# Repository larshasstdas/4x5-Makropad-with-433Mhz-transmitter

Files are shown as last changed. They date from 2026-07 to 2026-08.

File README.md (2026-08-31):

# 4x5-Makropad-with-433Mhz-transmitter

WhatsApp Image 2026-08-31 at 16 35 43

This project is about a Makropad that has 20 keys in a 4x5 matrix with a 433Mhz transmitter that is used to power my PC. Every key has an indiviually LED that will be changeable with an app on the PC.

---

## Motivation

In a previous project i made a [wireless power switch for my PC](https://github.com/larshasstdas/Remote-PC-Power-Switch) but as it is only a singular button it feels quite chunky. And i also always had the interest in controlling my LED strips in my room and my PC lighting i got the idea of making a makropad that combines all those features. It should also have usual makropad funktion like adjusting the sound volume and shortcuts. 

---

## How it works

The RP2040 registers which key is pressed. It send that information to a daemon on my pc which has the information of what that key actually does. The programm can also send information to the makropad to what each LED should be. If the button is pressed that is used for turning the PC on the daemon can't answer because the PC is turned of. If the RP2040 does not get a signal back it sends the signal to the stx882 module resulting in turning the PC on. It can use a different function afterwards because the daemon can answer if that button is pressed.

---

## PCB

I am using the RP2040 as a microcontroller it has everything i need and can be soldered onto the pcb with castelladed pads. The same goes for the 433MHz transmitter module the STX882. I also have the option to add a display but I am leaving that open as of now. Furthermore there are Hotswap pockets so i can easily spwap broken switches. And for the LED I am using the SK6812MINI-E, a reverse mount LED. The switches are using a matrix so they need less pins and the LEDs are in an addressable LED chain.

All the PCB files are in the KiCad Folder.



---

## Bill of Materials

Bought the parts so they would be as cheap as possible. Did not buy the display pins as i do not plan on using it for now. It is just an option for the future.

| Part | Description | Qty | Unit Price | Link |
| --- | --- | --- | --- | ---- |
| Waveshare RP2040-Zero | MCU module, USB-C, castellated | 1 | 4.00€ | [Eckstein](https://eckstein-shop.de/WaveShare-RP2040-Zero-MCU-Board-Mini-Version) |
| STX882 | 433 MHz ASK/OOK transmitter (+ spring antenna) | 1 | 6.99€ | [Amazon](https://www.amazon.de/dp/B0D3TGHD7H/) |
| SK6812MINI-E | Addressable RGB LED, reverse mount | 20  | 6.59€ | [Amazon](https://www.amazon.de/gp/product/B0DQ8HXSQS/) |
| 74AHCT1G125 | Level shifter 3.3V→5V for LED data line (SOT-353) | 1 | 0.20€ | [Reichelt](https://www.reichelt.de/de/de/shop/produkt/tristate-buffer_enable_2_5_5_v_sot-353-5-219156) |
| Gateron Pro Milky Yellow  | Linear 5-pin hotswap switch | 20  | 6.80€ | [inputgear](https://inputgear.de/products/gateron-pro-milky-yellow-switch?variant=56226523775320) |
| Kailh MX Hotswap Socket | MX hotswap socket (THT) | 20  | 7.83€ | [Amazon](https://www.amazon.de/gp/product/B07K8CCMQZ/) |
| Keycaps 1u | Opaque keycaps (light shows around base) | 20  | 10.71€ | [Amazon](https://www.amazon.de/gp/product/B0F1YQGJ35/) |
| 1N4148W | Matrix diode, 100V 150mA (SOD-123) | 20  | 0.40€ | [Reichelt](https://www.reichelt.de/de/de/shop/produkt/kleinsignal-schalt-diode_100_v_150_ma_sod-123-219382) |
| 100nF capacitor | Decoupling, X7R 50V (0603) | 21  | 0.63€ | [Reichelt](https://www.reichelt.de/de/de/shop/produkt/mlcc_0603_100nf_50v_x7r_-5_-429035) |
| 330 Ω resistor | LED data-line series resistor (0603) | 1 | 0.02€ | [Reichelt](https://www.reichelt.de/de/de/shop/produkt/smd-widerstand_0603_330_ohm_100_mw_1_-89424) |
| I2C display header | 4-pin Dupont, optional display (2.54mm) | 1 | - | – |
| PCB | pcb ordered on jlcpcb | 1 | 33.67€ | – |
| 3D-printed case | Top + bottom, filament | 1 | ~1.00€ | – |
| **Total** | | | **78.84€** | |

---

## Case

The CAD files for the case are in the CAD folder. There are the source files from creo parametric (my cad tool), the step-files and the stl-files each in one folder. They contain a file for the top and the bottom part and the Creo folder also has the assembly file for the makropad which you can see below. The only files needed for 3D.printing are the case_bottom and cas_top files. The rest are only used for the assembly.



---

## How it is build

The pcb is soldered on a hot plate and some parts by soldering iron. The switches get placed into the hotswaps and once that is done it is placed in the bottom half of the case. Afterwards the top part gets fitted onto the bottom part and the keycaps get pressed onto the switches.

---

## How to flash

I used VS Code with platform.io to flash the RP2040. Just connect with an USB-C cable and press the flash button bottom left.

---

## How to set up the daemon

1. Create and activating the venv. For that first use "cd C:\path\...\Makropad\Daemon", then "python -m venv venv" and last "venv\Scripts\Activate.ps1".
2. Install all the libarys. The versions are in the requirements.txt
3. Select the right COM port in the config.json
4. Press "Win + R" and type "shell:startup" so the startup folder opens.
5. Rightclick and add a new shortcut. Enter the location "C:\path\...\Makropad\Daemon\venv\Scripts\pythonw.exe main.py" for the shortcut. When you press enter you can choose a name.
6. Rightclick the new shortcut and go to properties. In "Start in" enter the daemon folder "C:\path\...\Makropad\Daemon" it must not include "\venv\Scripts".
7. Apply the changes.

---

## Files

```
CAD/               Creo source files (top, bottom, pcb and assembly), stl files (top & bottom), step files
Deamon/            Python files for the daemon, requirements.txt with all the libary versions  
KiCad/             KiCad files, Gerber files (also as .zip), libarys, Pick&Place
RP2040_Code/       Platform.io project with all files needed for flashing the RP2040
BOM.csv
```

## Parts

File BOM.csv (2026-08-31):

Part,Description,Quantity,Price (EUR),Link
Waveshare RP2040-Zero,MCU module USB-C castellated (no-header variant),1,4.00,https://eckstein-shop.de/WaveShare-RP2040-Zero-MCU-Board-Mini-Version
STX882,433 MHz ASK/OOK transmitter module (+ spring antenna),1,6.99,https://www.amazon.de/dp/B0D3TGHD7H/
SK6812MINI-E,Addressable RGB LED with integrated driver (reverse mount),20,6.59,https://www.amazon.de/gp/product/B0DQ8HXSQS/
74AHCT1G125,Single tri-state buffer / level shifter 3.3V->5V (SOT-353-5),1,0.20,https://www.reichelt.de/de/de/shop/produkt/tristate-buffer_enable_2_5_5_v_sot-353-5-219156
Gateron Pro Milky Yellow,Linear 5-pin hotswap switch,20,6.80,https://inputgear.de/products/gateron-pro-milky-yellow-switch?variant=56226523775320
Kailh MX Hotswap Socket,MX hotswap socket (THT),20,7.83,https://www.amazon.de/gp/product/B07K8CCMQZ/
Keycaps 1u,Opaque keycaps (light shows around switch base),20,10.71,https://www.amazon.de/gp/product/B0F1YQGJ35/
1N4148W,Small-signal switching diode 100V 150mA (SOD-123),20,0.40,https://www.reichelt.de/de/de/shop/produkt/kleinsignal-schalt-diode_100_v_150_ma_sod-123-219382
100nF capacitor,Decoupling capacitor X7R 50V (0603),21,0.63,https://www.reichelt.de/de/de/shop/produkt/mlcc_0603_100nf_50v_x7r_-5_-429035
330 ohm resistor,Signal series resistor on LED data line (0603),1,0.02,https://www.reichelt.de/de/de/shop/produkt/smd-widerstand_0603_330_ohm_100_mw_1_-89424
I2C display header,4-pin Dupont header for optional display (2.54mm),1,,
PCB,pcb ordered on jlcpcb,1,33.67,
3D-printed case,Top + bottom halves | filament (files in CAD/),1,1.00,

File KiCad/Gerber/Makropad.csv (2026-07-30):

ID | Bezeichner | Footprint | Stückzahl | Bezeichnung | Anbieter und Referenz
1 | C1, C2, C3, C4, C5, C6, C7, C8, C9, C10, C11, C12, C13, C14, C15, C16, C17, C18, C19, C20, C21 | C_0603_1608Metric | 21 | 100n
2 | D1, D2, D3, D4, D5, D6, D7, D8, D9, D10, D11, D12, D13, D14, D15, D16, D17, D18, D19, D20 | D_SOD-123 | 20 | D
3 | D21, D22, D23, D24, D25, D26, D27, D28, D29, D30, D31, D32, D33, D34, D35, D36, D37, D38, D39, D40 | LED_SK6812MINI-E_3.2x2.8mm_P1.5mm_ReverseMount | 20 | SK6812MINI-E
4 | J1 | PinHeader_1x04_P2.54mm_Horizontal | 1 | Conn_01x04_Pin
5 | R1 | R_0603_1608Metric | 1 | 330
6 | SW1, SW2, SW3, SW4, SW5, SW6, SW7, SW8, SW9, SW10, SW11, SW12, SW13, SW14, SW15, SW16, SW17, SW18, SW19, SW20 | SW_Hotswap_Kailh_MX_1.00u | 20 | SW_Push
7 | U1 | rp2040-zero-smd | 1 | rp2040-zero
8 | U2 | SOT-353_SC-70-5 | 1 | 74AHCT1G125
9 | U3 | STX882 | 1 | ~

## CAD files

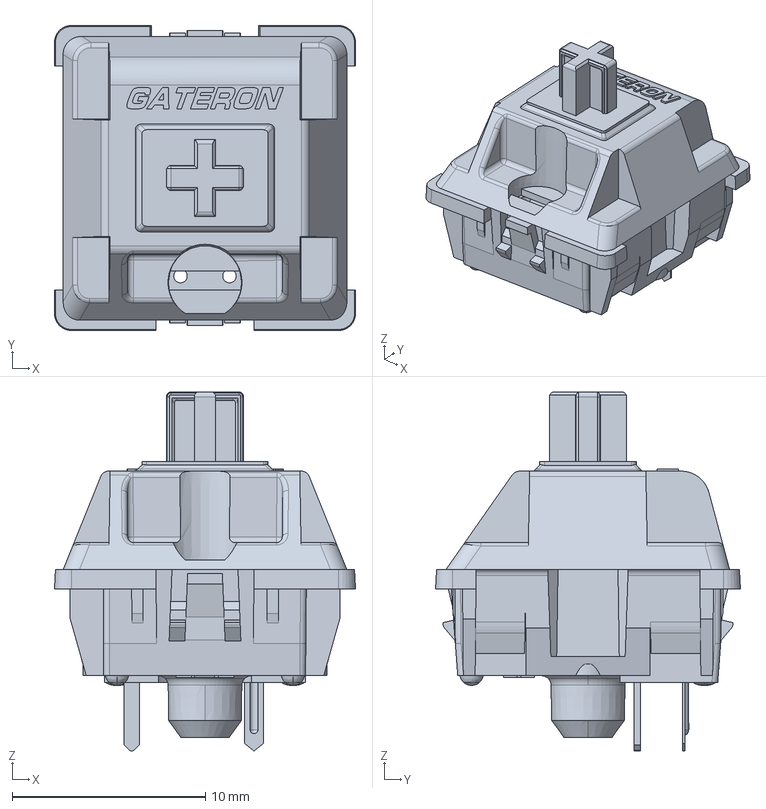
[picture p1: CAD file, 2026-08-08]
CAD/stp/KS-3X Full Black Switch KS-3A10B060NN-X.stp
15.6 x 15.8 x 18.6 mm

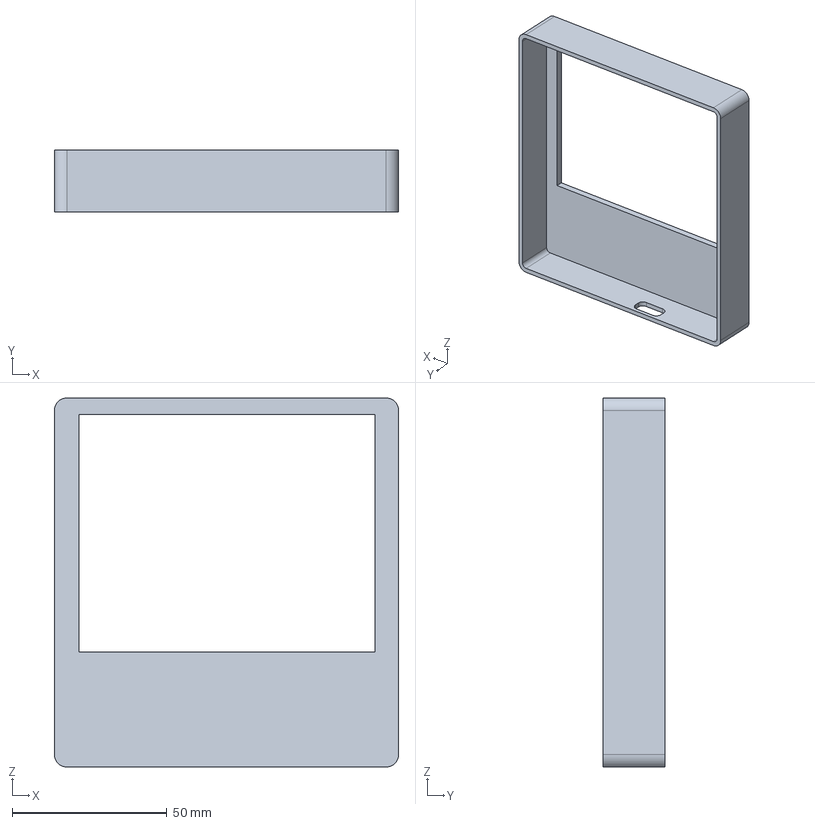
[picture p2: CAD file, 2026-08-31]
CAD/stp/case_top.stp
111.1 x 20.0 x 119.1 mm

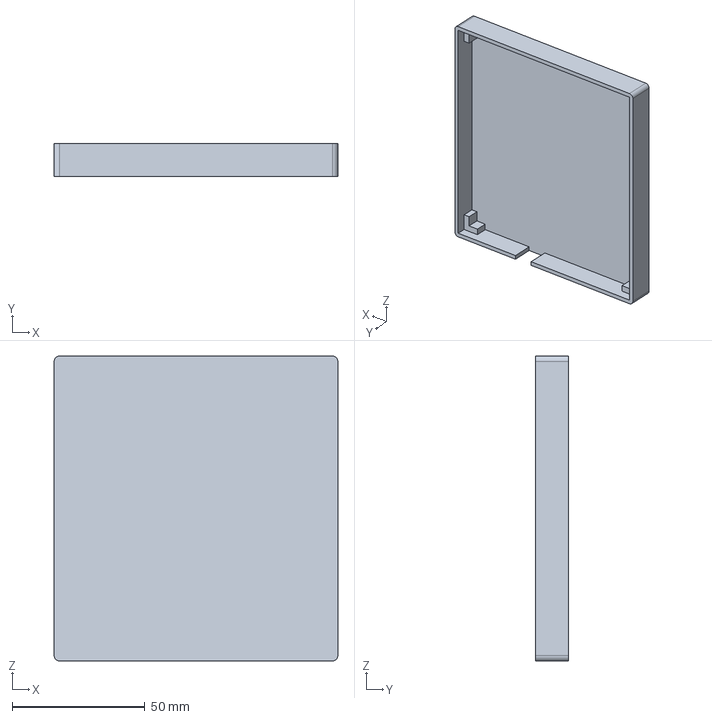
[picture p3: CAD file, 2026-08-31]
CAD/stp/case_bottom.stp
106.7 x 12.5 x 114.7 mm

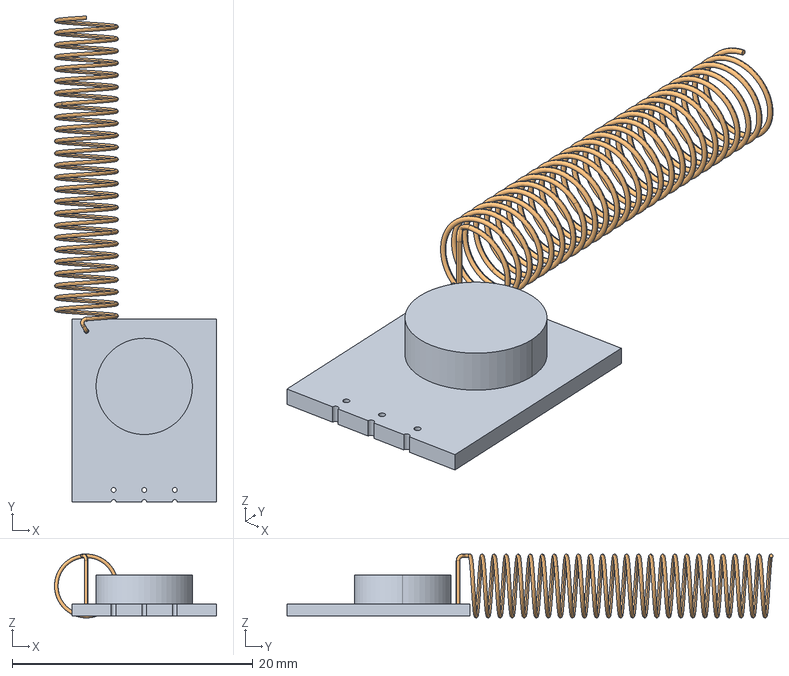
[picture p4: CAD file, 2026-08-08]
CAD/stp/stx882.stp
13.4 x 40.3 x 5.30 mm

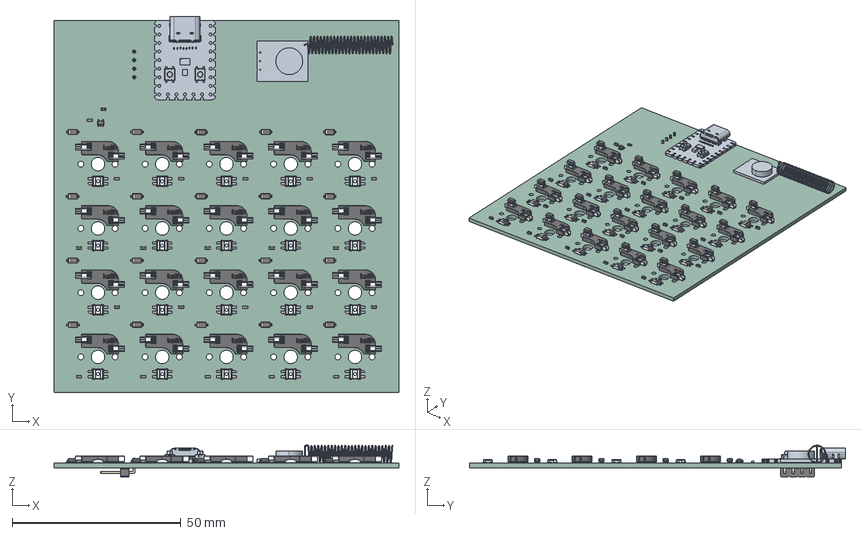
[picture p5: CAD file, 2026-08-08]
CAD/stp/PCB.step
102.3 x 111.5 x 9.37 mm
C_0603_1608Metric x 21
Pin1 x 20
Pin2 x 20
Pin3 x 20
Pin4 x 20
SOT-353_SC-70-5
D_SOD-123 x 20
PCB 1.20.1
stx882
R_0603_1608Metric
SW_Hotswap_Kailh_MX x 20
PinHeader_1x04_P2.54mm_Horizontal
Makropad_PCB

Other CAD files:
CAD/stl/case_bottom.stl
CAD/stl/case_top.stl

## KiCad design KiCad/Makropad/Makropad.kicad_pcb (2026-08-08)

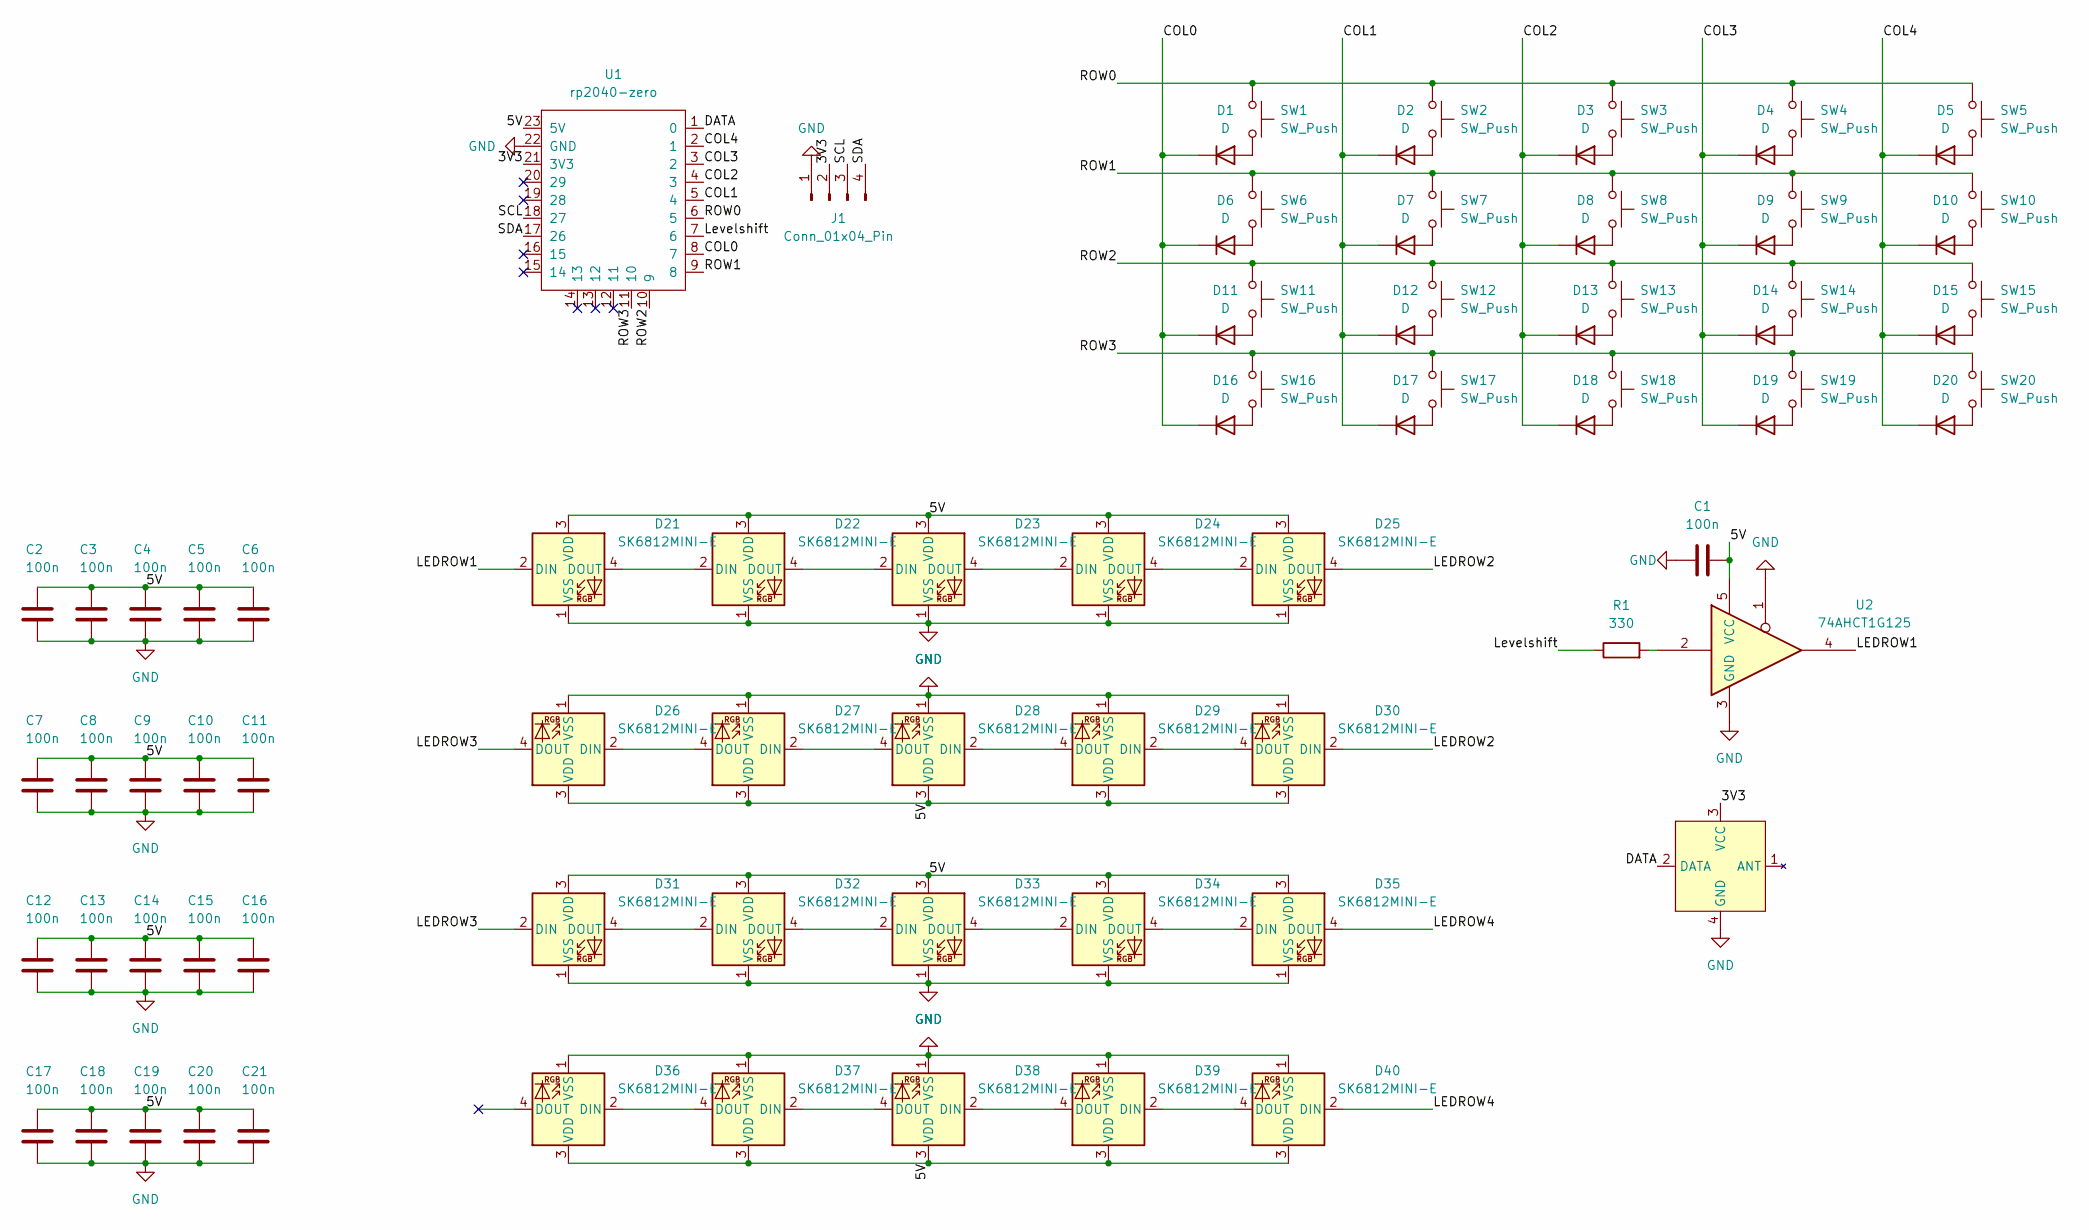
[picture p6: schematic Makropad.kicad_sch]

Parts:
C1, C2, C3, C4, C5, C6, C7, C8, C9, C10, C11, C12, C13, C14, C15, C16, C17, C18, C19, C20, C21: 100n; C_0603_1608Metric
D1, D2, D3, D4, D5, D6, D7, D8, D9, D10, D11, D12, D13, D14, D15, D16, D17, D18, D19, D20: D; D_SOD-123
D21, D22, D23, D24, D25, D26, D27, D28, D29, D30, D31, D32, D33, D34, D35, D36, D37, D38, D39, D40: SK6812MINI-E; LED_SK6812MINI-E_3.2x2.8mm_P1.5mm_ReverseMount
J1: Conn_01x04_Pin; PinHeader_1x04_P2.54mm_Horizontal
R1: 330; R_0603_1608Metric
SW1, SW2, SW3, SW4, SW5, SW6, SW7, SW8, SW9, SW10, SW11, SW12, SW13, SW14, SW15, SW16, SW17, SW18, SW19, SW20: SW_Push; SW_Hotswap_Kailh_MX_1.00u
U1: rp2040-zero; rp2040-zero-smd
U2: 74AHCT1G125; SOT-353_SC-70-5
U3: STX882

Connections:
/3V3: J1.2, U1.21 (3V3), U3.3 (VCC)
/5V: C1.2, C2.1, C3.1, C4.1, C5.1, C6.1, C7.1, C8.1, C9.1, C10.1, C11.1, C12.1, C13.1, C14.1, C15.1, C16.1, C17.1, C18.1, C19.1, C20.1, C21.1, D21.3 (VDD), D22.3 (VDD), D23.3 (VDD), D24.3 (VDD), D25.3 (VDD), D26.3 (VDD), D27.3 (VDD), D28.3 (VDD), D29.3 (VDD), D30.3 (VDD), D31.3 (VDD), D32.3 (VDD), D33.3 (VDD), D34.3 (VDD), D35.3 (VDD), D36.3 (VDD), D37.3 (VDD), D38.3 (VDD), D39.3 (VDD), D40.3 (VDD), U1.23 (5V), U2.5 (VCC)
/COL0: D1.1 (K), D6.1 (K), D11.1 (K), D16.1 (K), U1.8 (7)
/COL1: D2.1 (K), D7.1 (K), D12.1 (K), D17.1 (K), U1.5 (4)
/COL2: D3.1 (K), D8.1 (K), D13.1 (K), D18.1 (K), U1.4 (3)
/COL3: D4.1 (K), D9.1 (K), D14.1 (K), D19.1 (K), U1.3 (2)
/COL4: D5.1 (K), D10.1 (K), D15.1 (K), D20.1 (K), U1.2 (1)
/DATA: U1.1 (0), U3.2 (DATA)
/LEDROW1: D21.2 (DIN), U2.4
/LEDROW2: D25.4 (DOUT), D30.2 (DIN)
/LEDROW3: D26.4 (DOUT), D31.2 (DIN)
/LEDROW4: D35.4 (DOUT), D40.2 (DIN)
/Levelshift: R1.1, U1.7 (6)
/ROW0: SW1.1, SW2.1, SW3.1, SW4.1, SW5.1, U1.6 (5)
/ROW1: SW6.1, SW7.1, SW8.1, SW9.1, SW10.1, U1.9 (8)
/ROW2: SW11.1, SW12.1, SW13.1, SW14.1, SW15.1, U1.10 (9)
/ROW3: SW16.1, SW17.1, SW18.1, SW19.1, SW20.1, U1.11 (10)
/SCL: J1.3, U1.18 (27)
/SDA: J1.4, U1.17 (26)
GND: C1.1, C2.2, C3.2, C4.2, C5.2, C6.2, C7.2, C8.2, C9.2, C10.2, C11.2, C12.2, C13.2, C14.2, C15.2, C16.2, C17.2, C18.2, C19.2, C20.2, C21.2, D21.1 (VSS), D22.1 (VSS), D23.1 (VSS), D24.1 (VSS), D25.1 (VSS), D26.1 (VSS), D27.1 (VSS), D28.1 (VSS), D29.1 (VSS), D30.1 (VSS), D31.1 (VSS), D32.1 (VSS), D33.1 (VSS), D34.1 (VSS), D35.1 (VSS), D36.1 (VSS), D37.1 (VSS), D38.1 (VSS), D39.1 (VSS), D40.1 (VSS), J1.1, U1.22 (GND), U2.1, U2.3 (GND), U3.4 (GND)
unnamed: D1.2 (A), SW1.2
unnamed: D2.2 (A), SW2.2
unnamed: D3.2 (A), SW3.2
unnamed: D4.2 (A), SW4.2
unnamed: D5.2 (A), SW5.2
unnamed: D6.2 (A), SW6.2
unnamed: D7.2 (A), SW7.2
unnamed: D8.2 (A), SW8.2
unnamed: D9.2 (A), SW9.2
unnamed: D10.2 (A), SW10.2
unnamed: D11.2 (A), SW11.2
unnamed: D12.2 (A), SW12.2
unnamed: D13.2 (A), SW13.2
unnamed: D14.2 (A), SW14.2
unnamed: D15.2 (A), SW15.2
unnamed: D16.2 (A), SW16.2
unnamed: D17.2 (A), SW17.2
unnamed: D18.2 (A), SW18.2
unnamed: D19.2 (A), SW19.2
unnamed: D20.2 (A), SW20.2
unnamed: D21.4 (DOUT), D22.2 (DIN)
unnamed: D22.4 (DOUT), D23.2 (DIN)
unnamed: D23.4 (DOUT), D24.2 (DIN)
unnamed: D24.4 (DOUT), D25.2 (DIN)
unnamed: D26.2 (DIN), D27.4 (DOUT)
unnamed: D27.2 (DIN), D28.4 (DOUT)
unnamed: D28.2 (DIN), D29.4 (DOUT)
unnamed: D29.2 (DIN), D30.4 (DOUT)
unnamed: D31.4 (DOUT), D32.2 (DIN)
unnamed: D32.4 (DOUT), D33.2 (DIN)
unnamed: D33.4 (DOUT), D34.2 (DIN)
unnamed: D34.4 (DOUT), D35.2 (DIN)
unnamed: D36.2 (DIN), D37.4 (DOUT)
unnamed: D37.2 (DIN), D38.4 (DOUT)
unnamed: D38.2 (DIN), D39.4 (DOUT)
unnamed: D39.2 (DIN), D40.4 (DOUT)
unnamed: R1.2, U2.2

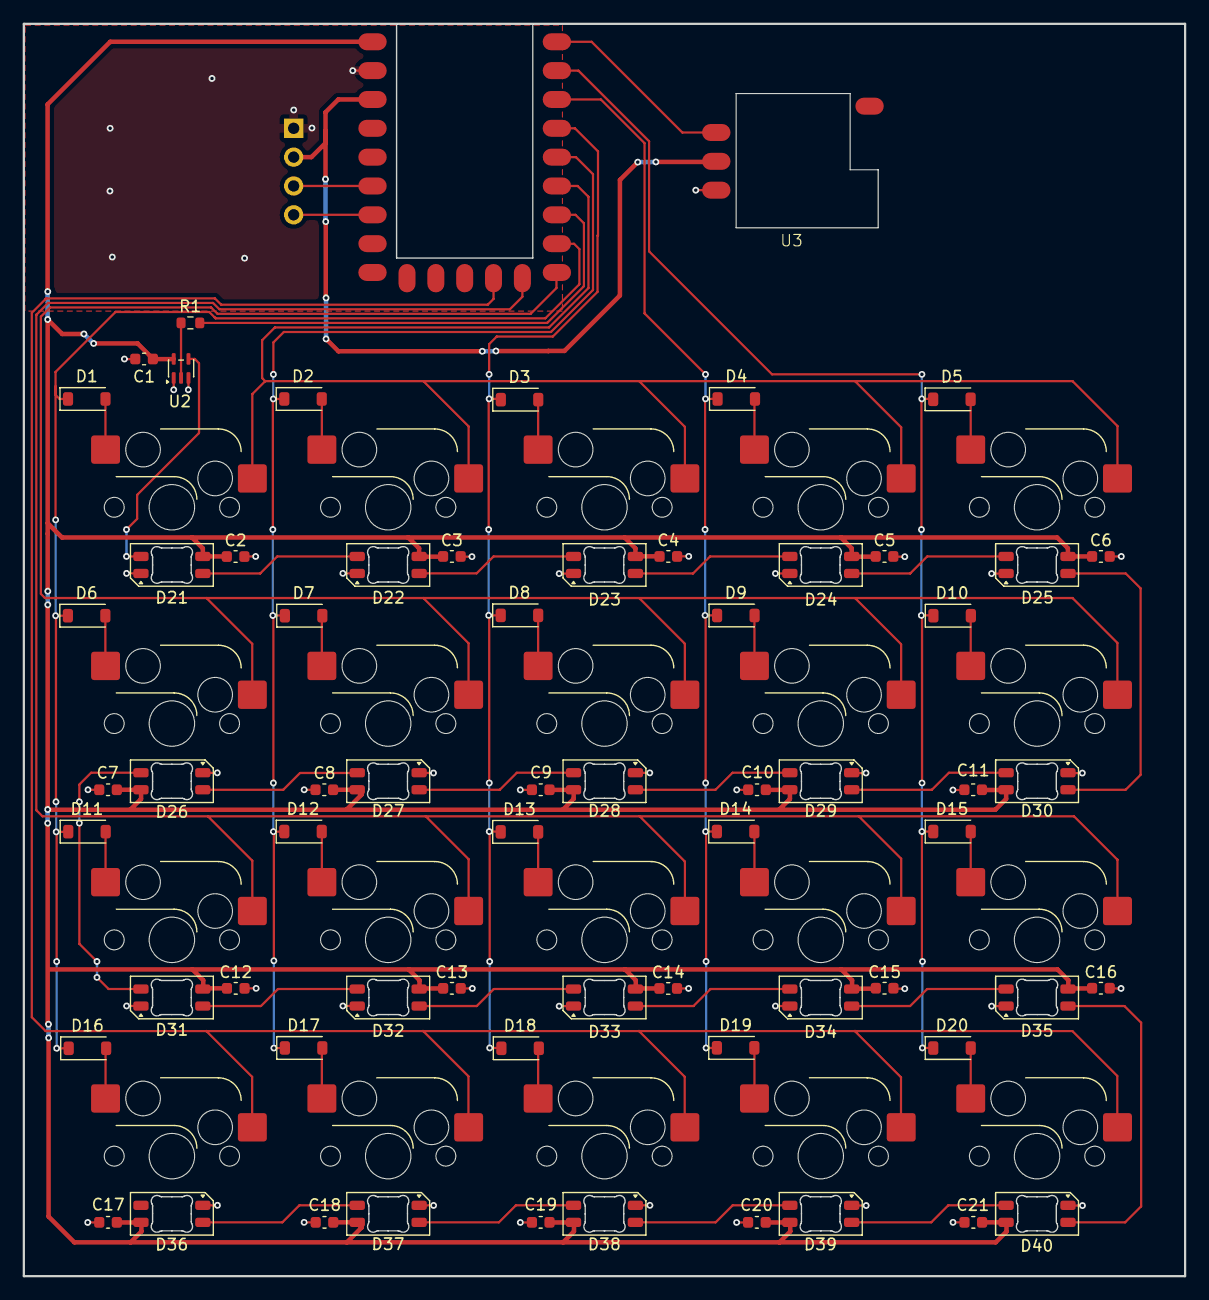
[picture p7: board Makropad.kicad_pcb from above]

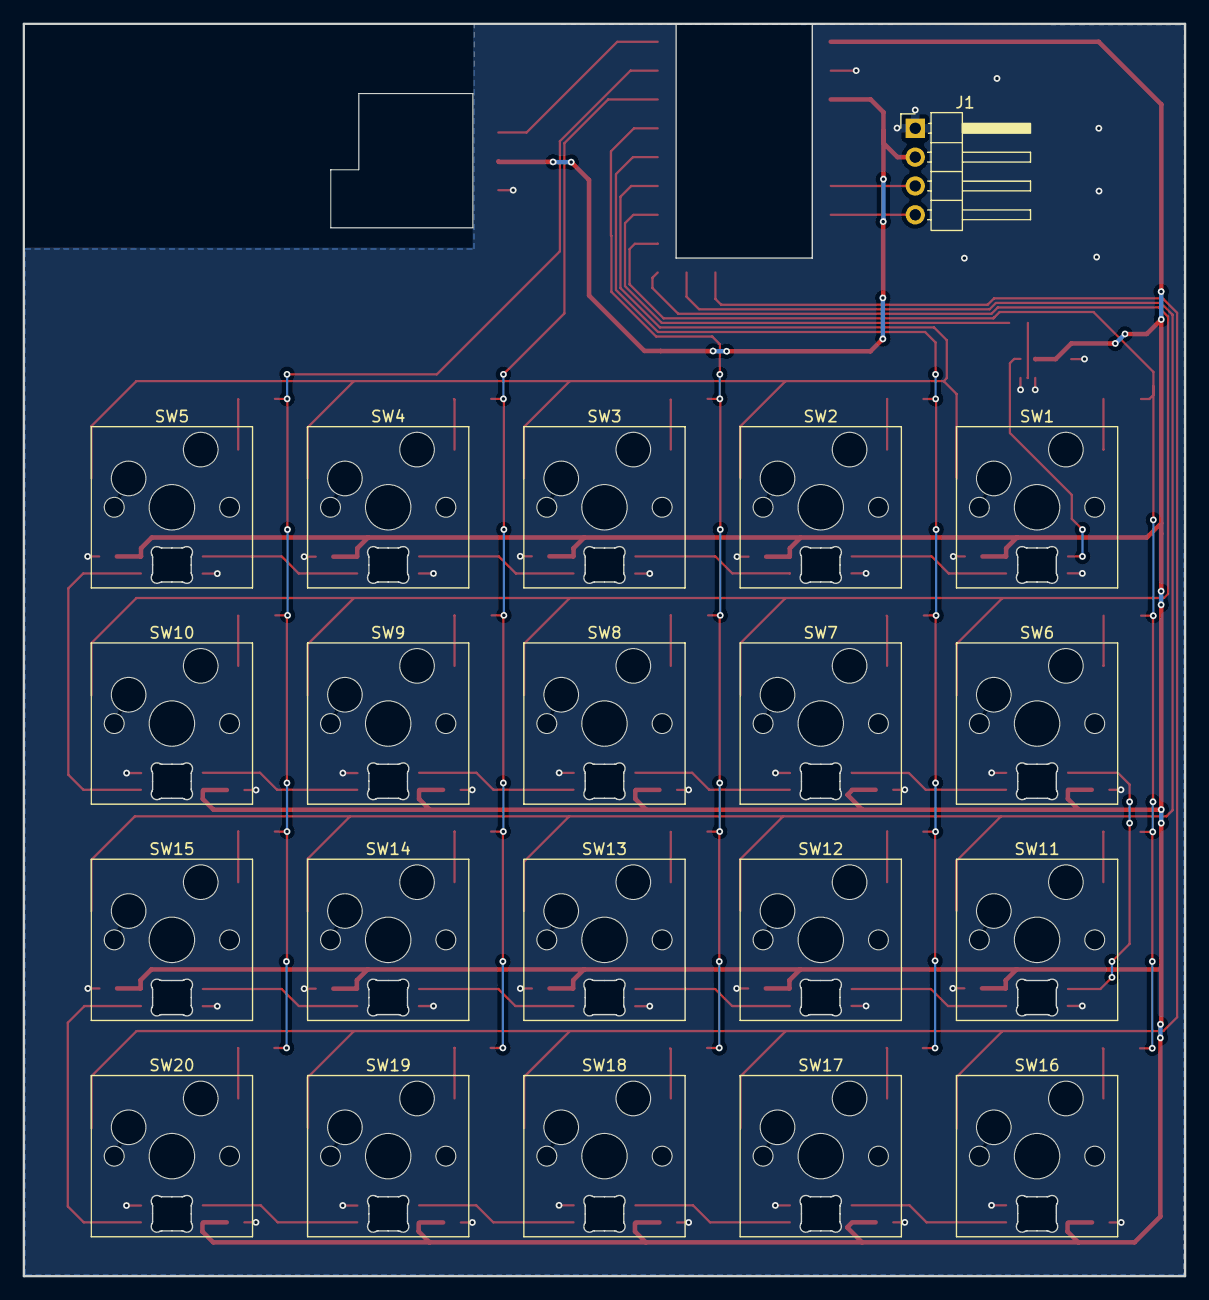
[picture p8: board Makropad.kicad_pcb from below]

Board: 2 copper layers, 102.3 x 110.3 mm, 86 parts (21 on the bottom side), 57 nets.

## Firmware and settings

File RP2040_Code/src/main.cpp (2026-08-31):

#include <Arduino.h>
#include <RCSwitch.h>

const int COLS = 5;
const int ROWS = 4;

const int colPINS[COLS] = {7, 4, 3, 2, 1};
const int rowPINS[ROWS] = {5, 8, 9, 10};

//bool keyState[ROWS][COLS] = {false};

volatile bool awake = false;

unsigned long lastPing = 0;
unsigned long lastPong = 0;

const unsigned long PING_INTERVAL = 2000;
const unsigned long PONG_SLEEP = 5000;

RCSwitch mySwitch = RCSwitch();
const unsigned long RF_CODE = 12345;
const int RF_BITS = 24;

bool buttonPressed(int &key);
void goToSleep();
void wakeToButton();
bool checkOnPC();
void startPC();


void setup() 
{
  Serial.begin(115200);
  lastPong = millis();

  for(int i = 0; i < COLS; i++)
  {
    pinMode(colPINS[i], OUTPUT);
    digitalWrite(colPINS[i], HIGH);
  }

  for(int i = 0; i < ROWS; i++)
  {
    pinMode(rowPINS[i], INPUT_PULLUP);
  }

  mySwitch.enableTransmit(0);
}


void loop()
{
  int key;
  unsigned long now = millis();

  if(now - lastPing >= PING_INTERVAL)
  {
    Serial.println("PING");
    lastPing = now;
  }

  if(Serial.available())
  {
    String msg = Serial.readStringUntil('\n');
    msg.trim();
    if(msg == "PONG")
    {
      lastPong = now;
    }
  }

  if(now - lastPong > PONG_SLEEP)
  {
    goToSleep();
    lastPong = millis();
  }

  if(buttonPressed(key))
  {
    if(key == 1)
    {
      if(!checkOnPC())
      {
        startPC();
      }
    }

    Serial.print("KEY_");
    Serial.println(key);
  }
  delay(5);
}

bool buttonPressed(int &key)
{
  static bool keyPressed = false;
  static unsigned long lastPressTime = 0;

  if (keyPressed && millis() - lastPressTime < 200) 
  {
    return false;
  }

  keyPressed = false;

  for(int i = 0; i < COLS; i++)
  {
    digitalWrite(colPINS[i], LOW);

    for(int j = 0; j < ROWS; j++)
    {
      if(digitalRead(rowPINS[j]) == LOW)
      {
        key = j*COLS + (COLS - 1 - i) + 1;
        keyPressed = true;
        lastPressTime = millis();
        digitalWrite(colPINS[i], HIGH);
        return true;
      }
    }
    digitalWrite(colPINS[i], HIGH);
  }
  return false;
}

void goToSleep()
{
  for(int i = 0; i < COLS; i++) {
    digitalWrite(colPINS[i], LOW);
  }

  for(int i = 0; i < ROWS; i++) {
    attachInterrupt(digitalPinToInterrupt(rowPINS[i]), wakeToButton, FALLING);
  }

  //TODO turn off LEDs

  awake = false;

  while(!awake)
  {
    __asm volatile ("wfi");
  }

  for(int i = 0; i < ROWS; i++) {
    detachInterrupt(digitalPinToInterrupt(rowPINS[i]));
  }

  for(int i = 0; i < COLS; i++) {
    digitalWrite(colPINS[i], HIGH);
  }
}

void wakeToButton()
{
  awake = true;
}

bool checkOnPC()
{
  Serial.println("PING");

  unsigned long time_of_ping = millis();

  while(millis() - time_of_ping < 500)
  {
    if(Serial.available())
    {
      String msg = Serial.readStringUntil('\n');
      msg.trim();
      if(msg == "PONG")
      {
        return true;
      }
    }
    delay(5);
  }
  return false;
}

void startPC()
{
  for (int i = 0; i < 5; i++) 
  {
    mySwitch.send(RF_CODE, RF_BITS);
    delay(5);
  }
}

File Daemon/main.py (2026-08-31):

from config import load_config
from serial_comm import connect, read_line, write_line
from actions import handle_key

def main():
    config = load_config()
    port = config["serial"]["port"]
    baudrate = config["serial"]["baudrate"]
    
    #print(f"Connecting with {port}...")
    connection = connect(port, baudrate)
    #print("Connected!")                       
    
    while True:

        try:
            line = read_line(connection)
        except ConnectionError:
            connection.close()
            connection = connect(port, baudrate)
            continue

        if line is None:
            continue
        

        # WakeUp Button
        if line == "PING":
            write_line(connection, "PONG")
            continue

        if line.startswith("KEY_"):
            handle_key(line, config)
        
        
if __name__ == "__main__":
    main()           

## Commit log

2026-07-30 added BOM
    [Makropad-B_Cu.gbr, Makropad-B_Mask.gbr, Makropad-B_Paste.gbr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]
2026-07-30 gitignore now lets .csv files through
    [BOM.csv, Makropad.csv, Pick&Place.csv]
2026-08-06 changed BOM
    [BOM.csv]
2026-08-08 full assembly
    [KS-3X Full Black Switch KS-3A10B060NN-X.stp, Makropad.kicad_pcb, PCB.step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]
2026-08-08 updated stl and stp files for top and bottom
    [case_bottom.stl, case_bottom.stp, case_top.stl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]
2026-08-31 Added code to run rp2040 and daemon
    [BOM.csv, case_bottom.stl, case_bottom.stp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]
2026-09-09 added LEDs with changable layouts and changed way of communication
